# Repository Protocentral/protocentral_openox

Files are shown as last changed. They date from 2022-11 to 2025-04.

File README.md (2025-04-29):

Protocentral OpenOx Wireless Pulse Sensor Kit based on AFE4400/ESP32
========================================

 

## Don't have one? [Buy it here](https://protocentral.com/product/protocentral-openox-pulse-oximeter-breakout-board-kit/)

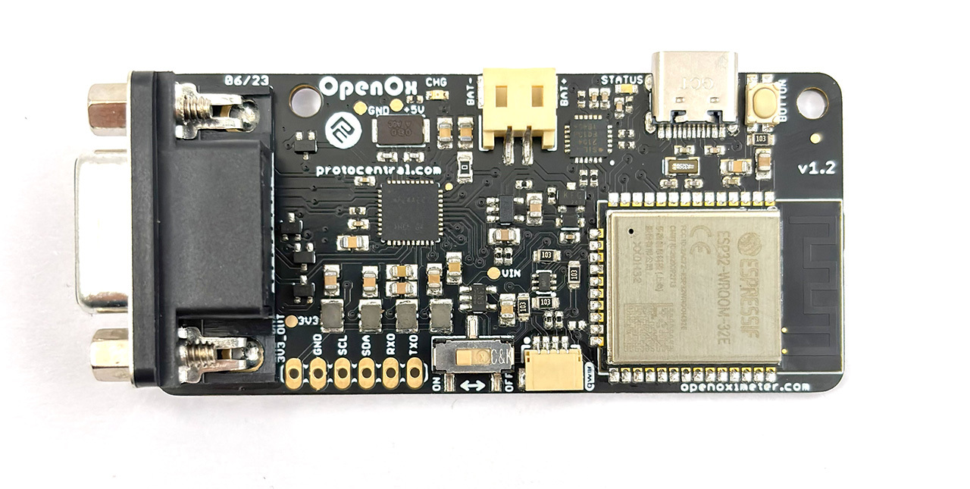
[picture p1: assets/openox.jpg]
Protocentral OpenOx Pulse Oximeter Breakout Board


Protocentral OpenOx is a new standalone, wireless pulse oximetry breakout board that is powered by the ubiquitous ESP32 WROOM32 module and uses the AFE4490 IC to measure oxygen levels in the blood while also providing a PPG waveform, heart rate, and SpO2 values measured with high precision. 

Protocentral OpenOx redefines mobility and wireless capabilities. It functions as a data acquisition system, allowing for continuous real-time monitoring of blood oxygen levels via BLE, which improves the user's medical care within his or her environment as well as medical research opportunities. The standard Nellcor probe is used, which is comfortable to wear, does not restrict the user's freedom of movement, and functions as a battery-powered standalone device.

## Hardware Setup

Connection with the Arduino board is as follows:

 |OpenOx pin label| Arduino Connection  |Pin Function      |
 |:-----------------: |:---------------------:|:------------------:|
 | Tx0              |  -                       |  Serial Data     |
 | RX0              |  -                        |  Serial Clock    |
 | SDA              |  SDA                        |  Power           |
 | SCL              |  SCL                      |  GND             |
 | GND              | GND                     |  Ground          |
 | 3V3              | 3V                      |  3V power supply |

# Visualizing Output

### USB Streaming

* Open the GUI, make sure to select **AFE4490 breakout** under the **Board** dropdown and the appropriate **Port**. If everything goes well, you will be able to see the screen as pictured above.

   <center>

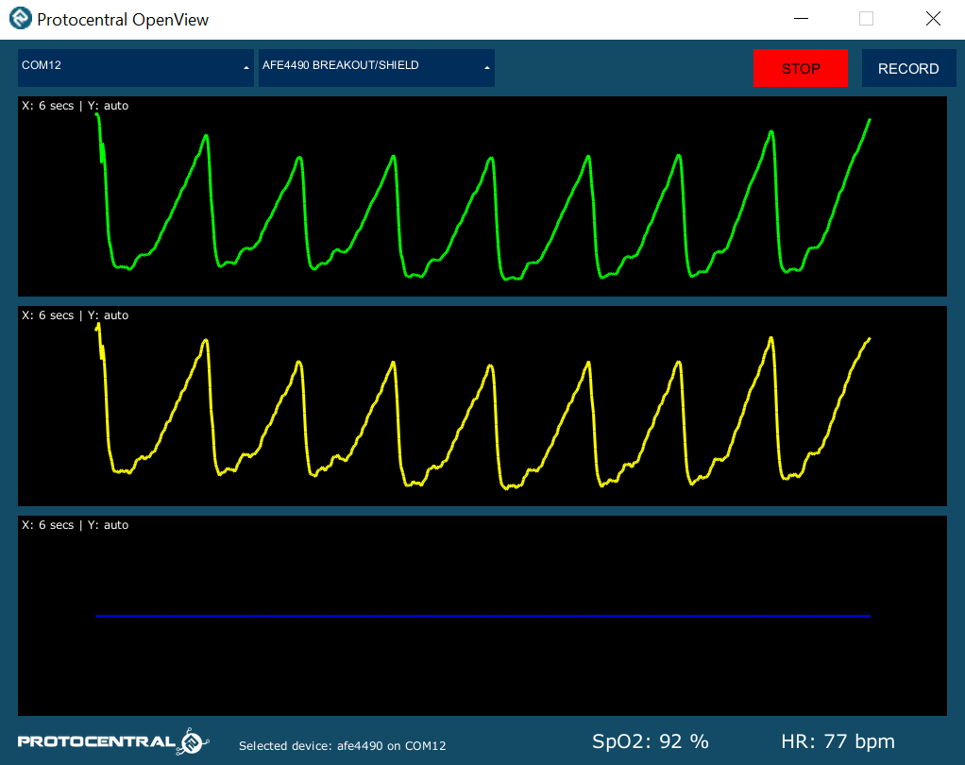
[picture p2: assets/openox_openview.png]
streaming vitals
  

  </center>

### BLE streaming

 <center>

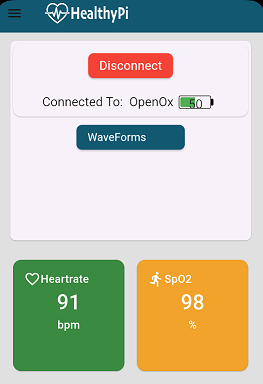
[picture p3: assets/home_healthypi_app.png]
Home
  

  </center>

 <center>

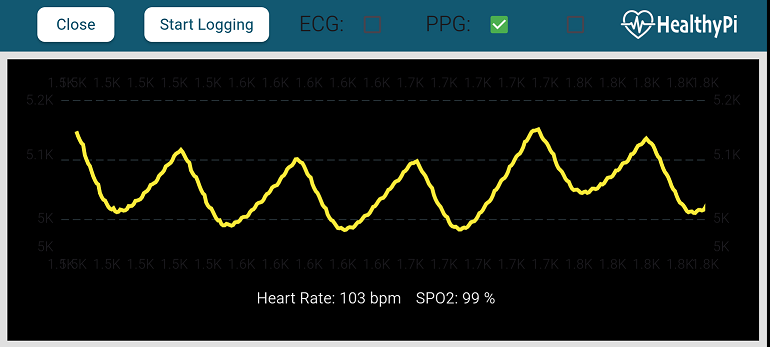
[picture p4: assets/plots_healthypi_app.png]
Plots
  

  </center>

## For further details, refer [the documentation on OpenOx Wireless Pulse Sensor](https://docs.protocentral.com/getting-started-with-openox/)

License Information
===================

License

This product is open source! Both, our hardware and software are open source and licensed under the following licenses:

Hardware
---------

**All hardware is released under the [CERN-OHL-P v2](https://ohwr.org/cern_ohl_p_v2.txt)** license.

Copyright CERN 2020.

This source describes Open Hardware and is licensed under the CERN-OHL-P v2.

You may redistribute and modify this documentation and make products
using it under the terms of the CERN-OHL-P v2 (https:/cern.ch/cern-ohl).
This documentation is distributed WITHOUT ANY EXPRESS OR IMPLIED
WARRANTY, INCLUDING OF MERCHANTABILITY, SATISFACTORY QUALITY
AND FITNESS FOR A PARTICULAR PURPOSE. Please see the CERN-OHL-P v2
for applicable conditions

Software
--------

**All software is released under the MIT License(http://opensource.org/licenses/MIT).**

THE SOFTWARE IS PROVIDED "AS IS", WITHOUT WARRANTY OF ANY KIND, EXPRESS OR IMPLIED, INCLUDING BUT NOT LIMITED TO THE WARRANTIES OF MERCHANTABILITY, FITNESS FOR A PARTICULAR PURPOSE AND NONINFRINGEMENT. IN NO EVENT SHALL THE AUTHORS OR COPYRIGHT HOLDERS BE LIABLE FOR ANY CLAIM, DAMAGES OR OTHER LIABILITY, WHETHER IN AN ACTION OF CONTRACT, TORT OR OTHERWISE, ARISING FROM, OUT OF OR IN CONNECTION WITH THE SOFTWARE OR THE USE OR OTHER DEALINGS IN THE SOFTWARE.

Documentation
-------------
**All documentation is released under [Creative Commons Share-alike 4.0 International](http://creativecommons.org/licenses/by-sa/4.0/).**


You are free to:

* Share — copy and redistribute the material in any medium or format
* Adapt — remix, transform, and build upon the material for any purpose, even commercially.
The licensor cannot revoke these freedoms as long as you follow the license terms.

Under the following terms:

* Attribution — You must give appropriate credit, provide a link to the license, and indicate if changes were made. You may do so in any reasonable manner, but not in any way that suggests the licensor endorses you or your use.
* ShareAlike — If you remix, transform, or build upon the material, you must distribute your contributions under the same license as the original.

Please check [*LICENSE.md*](LICENSE.md) for detailed license descriptions.

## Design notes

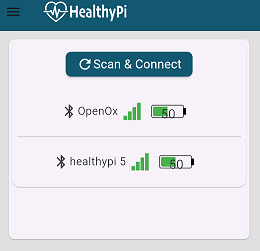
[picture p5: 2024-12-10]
assets/scan_healthypi_app.png

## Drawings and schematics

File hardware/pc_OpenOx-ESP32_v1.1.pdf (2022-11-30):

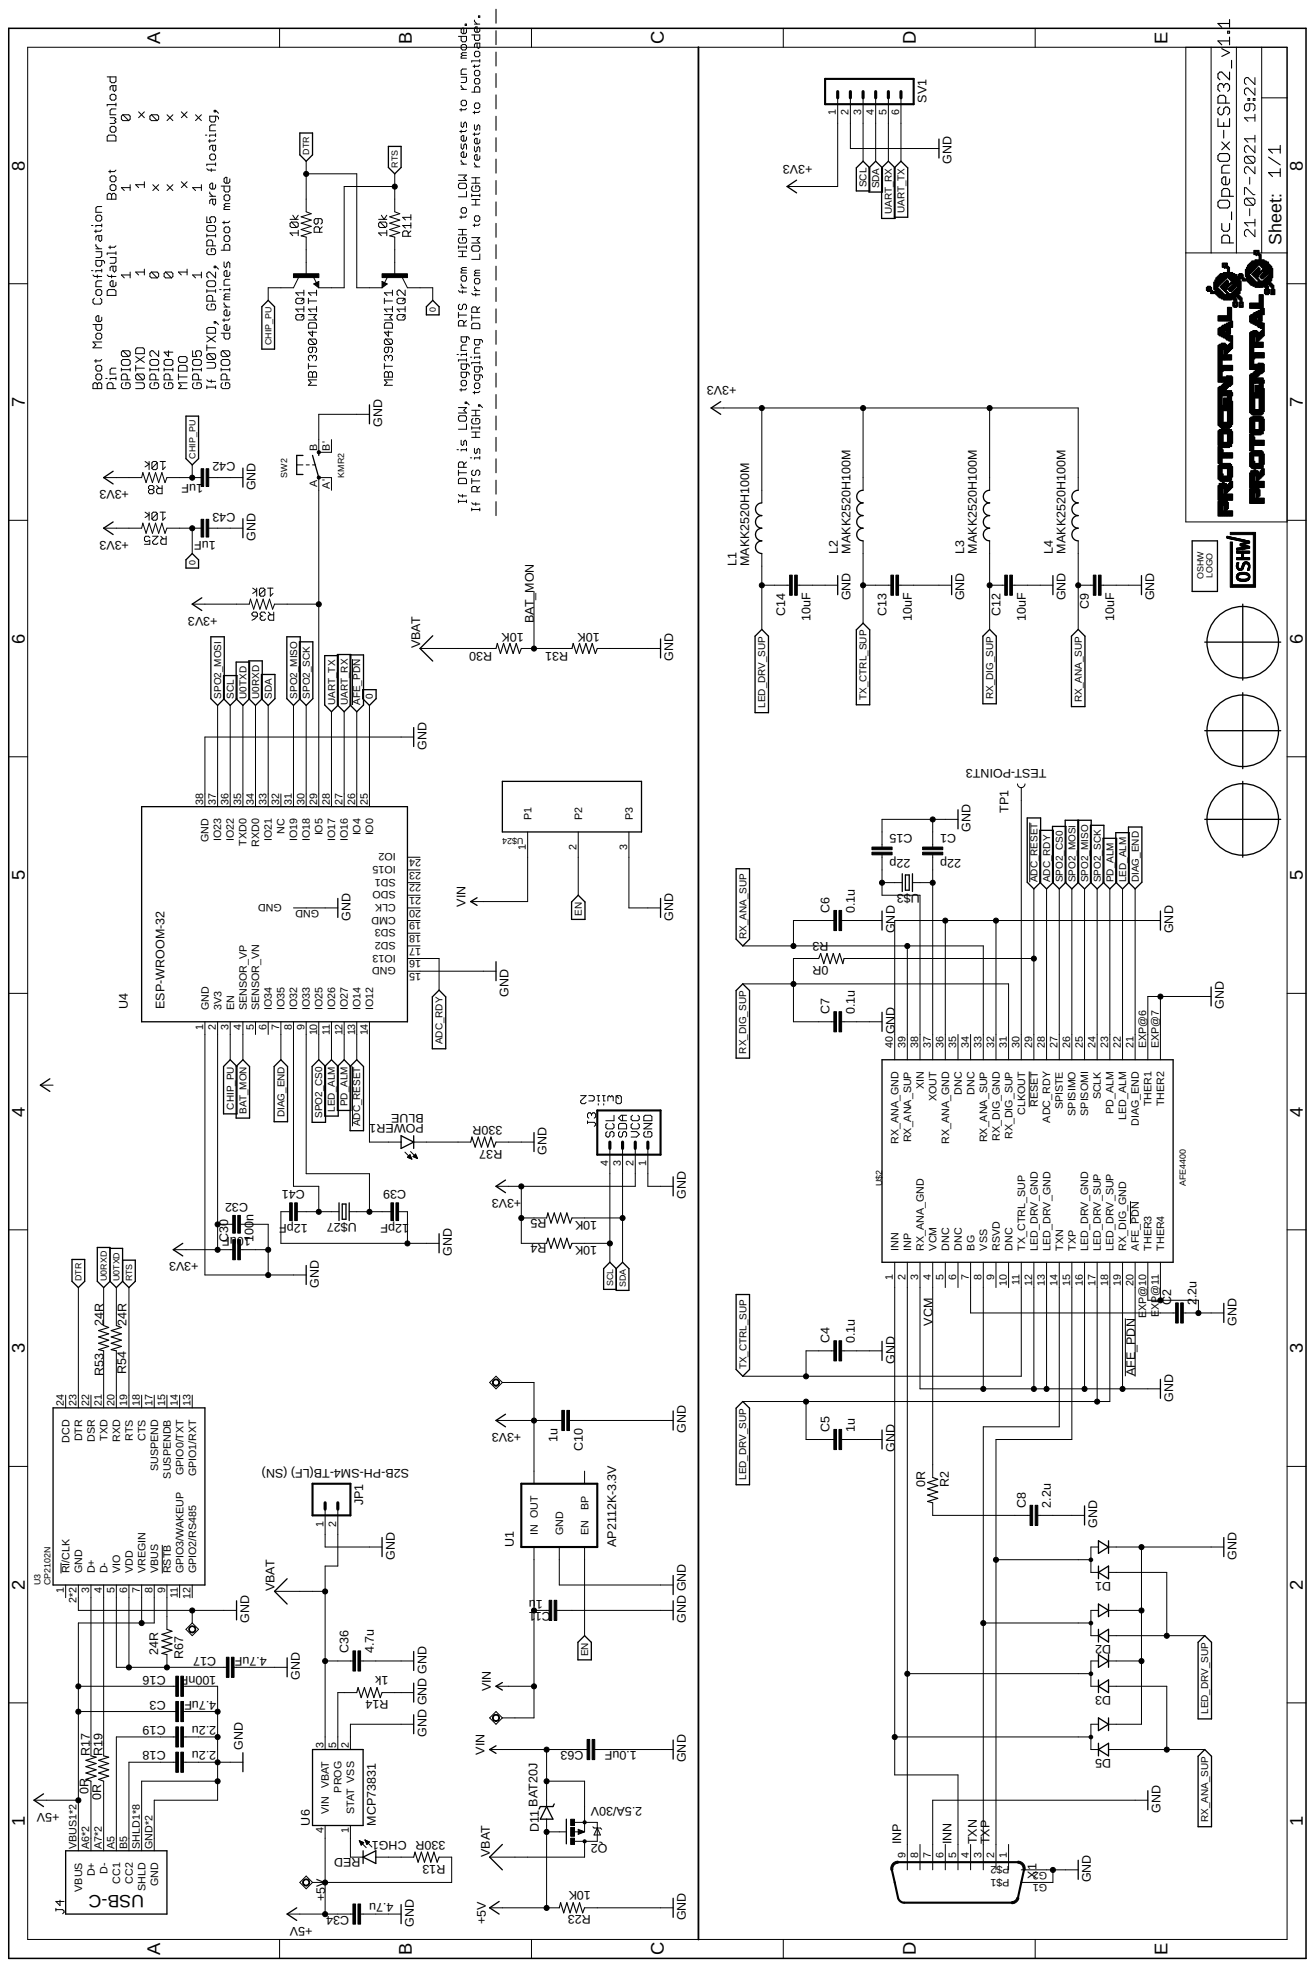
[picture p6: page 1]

THER1 EXP@6 THER2 EXP@7 THER3 EXP@10 THER4 EXP@11

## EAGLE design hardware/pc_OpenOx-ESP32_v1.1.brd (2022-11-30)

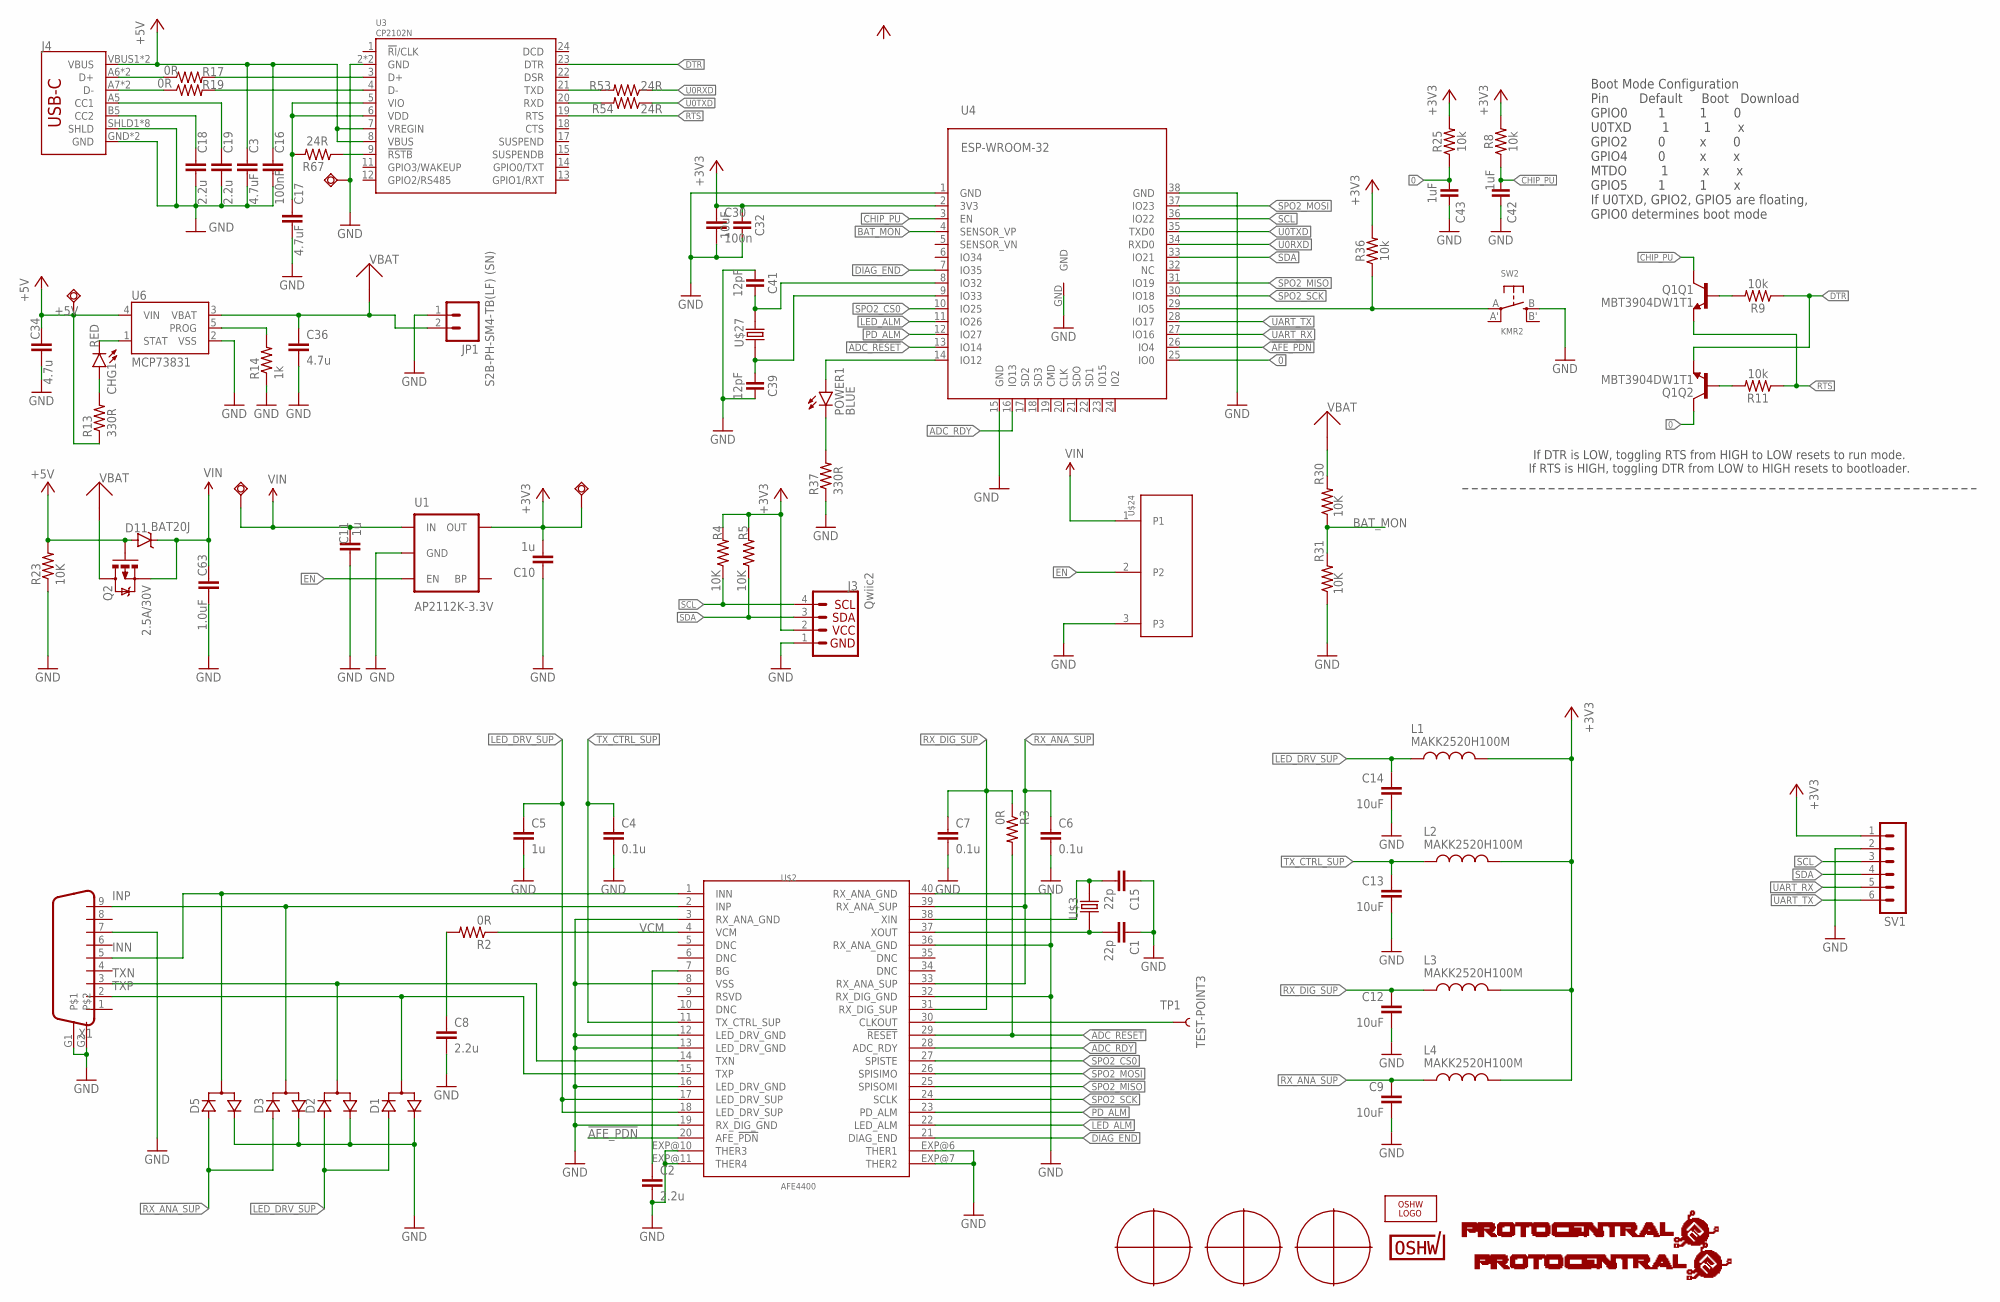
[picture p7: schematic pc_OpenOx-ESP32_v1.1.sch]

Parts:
C1, C15: 22p; C0402
C2, C8, C18, C19: 2.2u; C0402
C3, C17: 4.7uF; C0402
C4, C6, C7: 0.1u; C0805
C5, C10, C11: 1u; C0805
C9, C12, C13, C14, C32: 10uF; C0805
C16: 100nF; C0402
C30: 100n; C0805
C34, C36: 4.7u; C0805
C39, C41: 12pF; C0402
C42, C43: 1uF; C0402
C63: 1.0uF; C0402
CHG1: RED; CHIPLED_0603
D1, D2, D3, D5: D_ACACSOT323; SOT323
D11: BAT20J; SOD-323
J3: Qwiic2; 1X04_1MM_RA
J4: USB_C2-LAYER; USB-C-16P
JP1: S2B-PH-SM4-TB(LF) (SN); JST-2-SMD
L1, L2, L3, L4: MAKK2520H100M; INDC2520X100N
LOGO2: OSHW_LOGO_FILLX0200-NT; OSHW_FILLX200_NOTEXT
POWER1: BLUE; CHIPLED_0603
Q1: MBT3904DW1T1; SC70-6
Q2: 2.5A/30V; SOT23-3
R2, R17, R19: 0R; R0402
R3: 0R; R0805
R4, R5, R23, R30, R31: 10K; R0402
R8, R9, R11, R25, R36: 10k; 0603
R13, R37: 330R; R0402
R14: 1k; R0402
R53, R54, R67: 24R; R0402
SV1: MA06-1
SW2: KMR2; BTN_KMR2_4.6X2.8
SWIO1, SWIO2, SWIO3, SWIO17: TPSQTP13R; TP13R
TP1: TEST-POINT3; PAD.03X.03
U1: AP2112K-3.3V; SOT23-5
U3: CP2102N; QFN24
U4: ESP-WROOM-32
U6: MCP73831; SOT23-5
U$2: AFE4400; QFN-40
U$3: ABM3
U$4: PROTY_LOGO_WITH_TEXT; PROTY_WITH_TEXT
U$5: PROTY-LOGO; LOGO-PROTY
U$7: CERT-SMALL; CERT-SMALL-SILK
U$24: JS102011SCQN
U$27: 520-327-12.5-34B(32.768KHZ); ECX-31B
U$33, U$34, U$35: FUDCIALPOINTS; FIDUCIALPOINTS
X1: DB9

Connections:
0: C43.1, Q1.6 (C), R25.1, U4.25 (IO0)
3.3V: C17.1, R67.2, U3.5 (VIO), U3.6 (VDD)
!ADC_RESET: R3.2, U4.13 (IO14), U$2.29 (!RESET)
!AFE_PDN: U4.26 (IO4), U$2.20 (AFE_!PDN)
+3V3: C10.2, C30.1, C32.1, J3.2, L1.2, L2.2, L3.2, L4.2, R4.2, R5.2, R8.2, R25.2, R36.2, SV1.1, SWIO1.TP, U1.5 (OUT), U4.2 (3V3)
+5V: C3.1, C16.1, C34.1, D11.A, J4.VBUS1 (VBUS), J4.VBUS2 (VBUS), Q2.1 (G), R13.1, R23.2, SWIO3.TP, U3.7 (VREGIN), U3.8 (VBUS), U6.4 (VIN)
ADC_RDY: U4.16 (IO13), U$2.28 (ADC_RDY)
BAT_MON: R30.1, R31.2, U4.4 (SENSOR_VP)
CHIP_PU: C42.1, Q1.3 (C), R8.1, U4.3 (EN)
DIAG_END: U4.7 (IO35), U$2.21 (DIAG_END)
DTR: Q1.1 (E), R9.1, U3.23 (DTR)
EN: U1.3 (EN), U$24.2
GND: C1.1, C2.2, C3.2, C4.2, C5.2, C6.2, C7.2, C8.2, C9.2, C10.1, C11.1, C12.2, C13.2, C14.2, C15.1, C16.2, C17.2, C18.2, C19.2, C30.2, C32.2, C34.2, C36.2, C39.2, C41.1, C42.2, C43.2, C63.2, D1.2 (C), D2.2 (C), D3.2 (C), D5.2 (C), J3.1, J4.GND, J4.GND2 (GND), J4.SHLD1 (SHLD), J4.SHLD2 (SHLD), J4.SHLD3 (SHLD), J4.SHLD4 (SHLD), J4.SHLD5 (SHLD), J4.SHLD6 (SHLD), J4.SHLD7 (SHLD), J4.SHLD8 (SHLD), JP1.1, R14.1, R23.1, R31.1, R37.1, SV1.2, SW2.B (S), SWIO17.TP, U1.2 (GND), U3.2 (GND), U3.PAD (GND), U4.1 (GND), U4.15 (GND), U4.38 (GND), U4.GND, U6.2 (VSS), U$2.3 (RX_ANA_GND), U$2.8 (VSS), U$2.12 (LED_DRV_GND), U$2.13 (LED_DRV_GND), U$2.16 (LED_DRV_GND), U$2.19 (RX_DIG_GND), U$2.32 (RX_DIG_GND), U$2.36 (RX_ANA_GND), U$2.40 (RX_ANA_GND), U$2.EXP@6 (THER1), U$2.EXP@7 (THER2), U$2.EXP@10 (THER3), U$2.EXP@11 (THER4), U$24.3, X1.7, X1.G1, X1.G2
INN: D5.1 (CA), U$2.1 (INN), X1.5
INP: D3.1 (CA), U$2.2 (INP), X1.9
LED_ALM: U4.11 (IO26), U$2.22 (LED_ALM)
LED_DRV_SUP: C5.1, C14.1, D1.3 (A), D2.3 (A), L1.1, U$2.17 (LED_DRV_SUP), U$2.18 (LED_DRV_SUP)
unnamed: C1.2, U$2.37 (XOUT), U$3.1
unnamed: R67.1, U3.9 (!RSTB)
unnamed: C8.1, R2.2
unnamed: C19.1, J4.A5 (CC1)
unnamed: C18.1, J4.B5 (CC2)
unnamed: R17.2, U3.3 (D+)
unnamed: R19.2, U3.4 (D-)
unnamed: J4.A6 (D+), J4.B6 (D+), R17.1
unnamed: C15.2, U$2.38 (XIN), U$3.2
unnamed: C2.1, U$2.7 (BG)
unnamed: J4.A7 (D-), J4.B7 (D-), R19.1
unnamed: TP1.P$1, U$2.30 (CLKOUT)
unnamed: Q1.5 (B), R9.2
unnamed: Q1.2 (B), R11.2
unnamed: CHG1.C, U6.1 (STAT)
unnamed: CHG1.A, R13.2
unnamed: R14.2, U6.5 (PROG)
unnamed: C41.2, U4.8 (IO32), U$27.P$2 (2)
unnamed: C39.1, U4.9 (IO33), U$27.P$1 (1)
unnamed: R36.1, SW2.A, U4.29 (IO5)
unnamed: POWER1.A, U4.14 (IO12)
unnamed: POWER1.C, R37.2
PD_ALM: U4.12 (IO27), U$2.23 (PD_ALM)
RTS: Q1.4 (E), R11.1, U3.19 (RTS)
RX: R54.2, U3.20 (RXD)
RX_ANA_SUP: C6.1, C9.1, D3.3 (A), D5.3 (A), L4.1, U$2.33 (RX_ANA_SUP), U$2.39 (RX_ANA_SUP)
RX_DIG_SUP: C7.1, C12.1, L3.1, R3.1, U$2.31 (RX_DIG_SUP)
SCL: J3.4, R4.1, SV1.3, U4.36 (IO22)
SDA: J3.3, R5.1, SV1.4, U4.33 (IO21)
SPO2_CS0: U4.10 (IO25), U$2.27 (SPISTE)
SPO2_MISO: U4.31 (IO19), U$2.25 (SPISOMI)
SPO2_MOSI: U4.37 (IO23), U$2.26 (SPISIMO)
SPO2_SCK: U4.30 (IO18), U$2.24 (SCLK)
TX: R53.2, U3.21 (TXD)
TXN: D2.1 (CA), U$2.14 (TXN), X1.3
TXP: D1.1 (CA), U$2.15 (TXP), X1.2
TX_CTRL_SUP: C4.1, C13.1, L2.1, U$2.11 (TX_CTRL_SUP)
U0RXD: R53.1, U4.34 (RXD0)
U0TXD: R54.1, U4.35 (TXD0)
UART_RX: SV1.5, U4.27 (IO16)
UART_TX: SV1.6, U4.28 (IO17)
VBAT: C36.1, JP1.2, Q2.3 (D), R30.2, U6.3 (VBAT)
VCM: R2.1, U$2.4 (VCM)
VIN: C11.2, C63.1, D11.C, Q2.2 (S), SWIO2.TP, U1.1 (IN), U$24.1

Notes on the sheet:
Boot Mode Configuration Pin Default Boot Download GPIO0 1 1 0 U0TXD 1 1 x GPIO2 0 x 0 GPIO4 0 x x MTDO 1 x x GPIO5 1 1 x If U0TXD, GPIO2, GPIO5 are floating, GPIO0 determines boot mode
If DTR is LOW, toggling RTS from HIGH to LOW resets to run mode. If RTS is HIGH, toggling DTR from LOW to HIGH resets to bootloader.

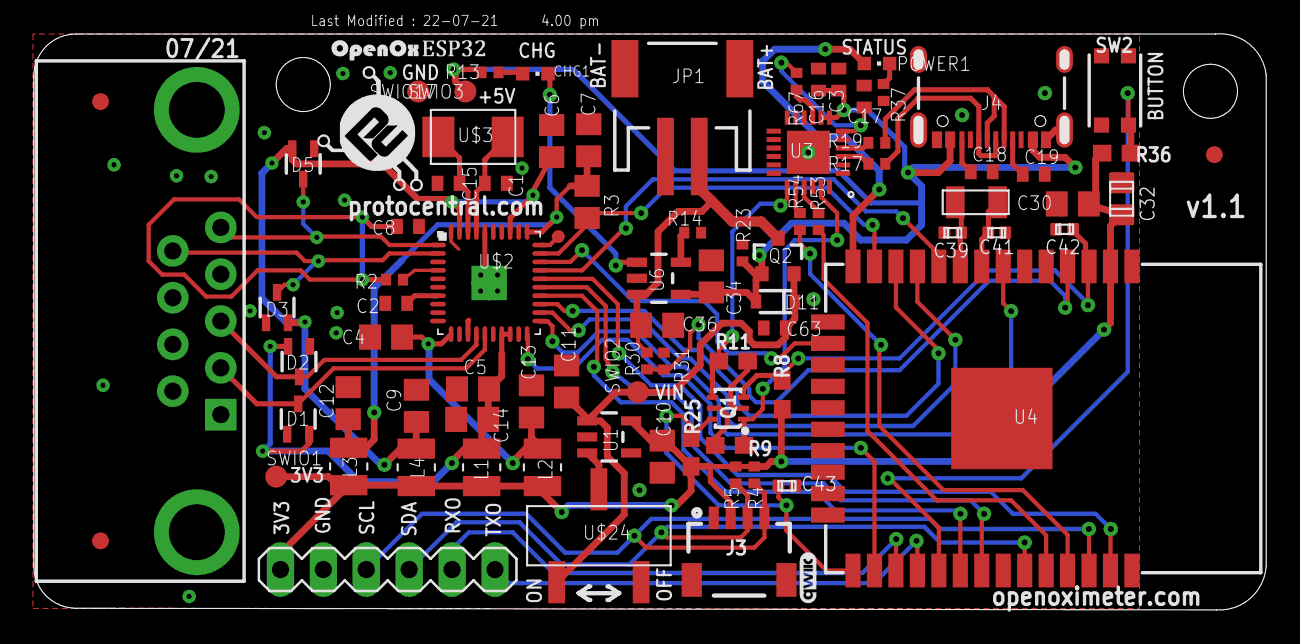
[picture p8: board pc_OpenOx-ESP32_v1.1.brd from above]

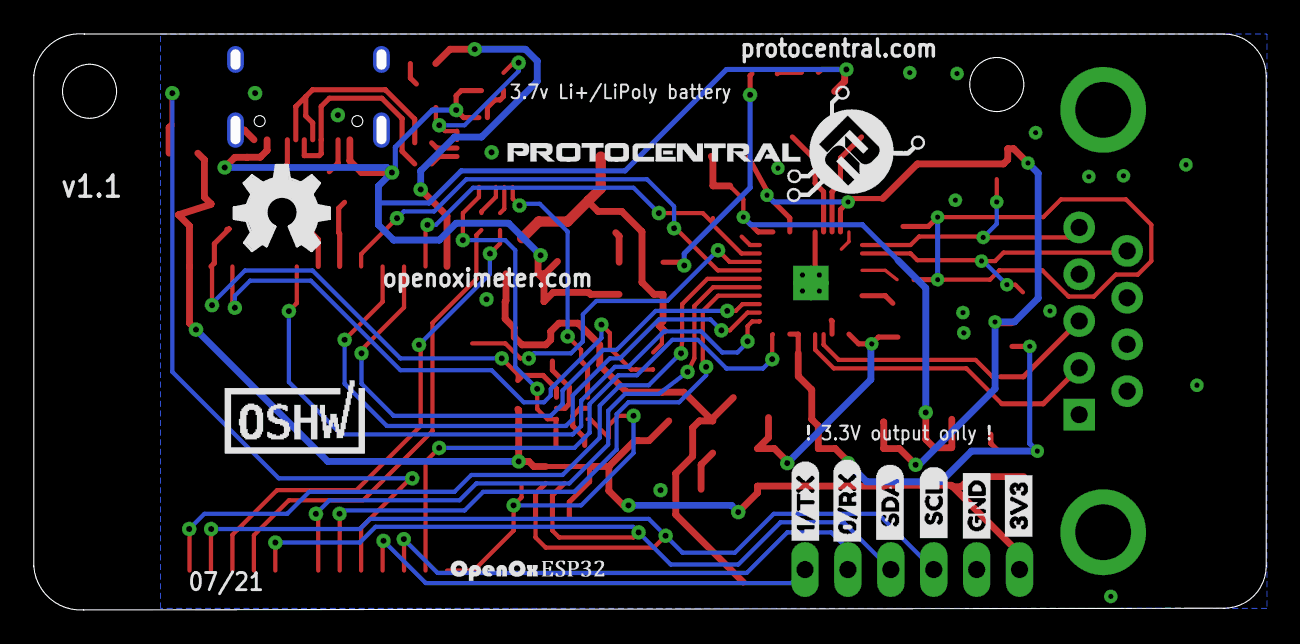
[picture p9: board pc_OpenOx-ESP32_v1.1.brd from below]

Board: 4 copper layers, 73.0 x 34.1 mm, 97 parts (11 on the bottom side), 61 nets.

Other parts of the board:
LOGO4: QWIIC_LOGO_3MM; QWIIC_3MM
U$6: 3V32
U$8, U$12: OPENOXLOGO1
U$9: _SCL16
U$10: _SDA17
U$13: GND0
U$16: PULSE
U$44: 1#TX1
U$48: 0#RX0

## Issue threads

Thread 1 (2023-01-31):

Incorrect HR

yashm, 2023-01-31:
Hello folks,
The OpenOx-USB-Output prints an incorrect heart rate.,
SPO2 is close to actual, but HR is way off:
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

Any pointers on what parameters to tweak?

protocentralashwin, 2023-01-31:
Thank you for reporting @yashm We will check and get back

yashm, 2023-01-31:
Thank you @protocentralashwin , will post some other minor PCB changes that I would recommend once this is solved.

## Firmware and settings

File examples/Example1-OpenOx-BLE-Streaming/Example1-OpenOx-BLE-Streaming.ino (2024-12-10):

//////////////////////////////////////////////////////////////////////////////////////////
//
//    This example is for the new Open-Ox board.
//
//    This software is licensed under the MIT License(http://opensource.org/licenses/MIT).
//
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
//   For information on how to use, visit https://github.com/Protocentral/protocentral-afe4490-arduino
/////////////////////////////////////////////////////////////////////////////////////////


#include <SPI.h>
#include <protocentral_afe44xx.h>

#include <BLEDevice.h>
#include <BLEServer.h>
#include <BLEUtils.h>
#include <BLE2902.h>

#define Heartrate_SERVICE_UUID (uint16_t(0x180D))
#define Heartrate_CHARACTERISTIC_UUID (uint16_t(0x2A37))
#define sp02_SERVICE_UUID (uint16_t(0x1822))
#define sp02_CHARACTERISTIC_UUID (uint16_t(0x2A5E))
#define HRV_SERVICE_UUID "cd5c7491-4448-7db8-ae4c-d1da8cba36d0"
#define HIST_CHARACTERISTIC_UUID "cd5c1525-4448-7db8-ae4c-d1da8cba36d0"
#define DATASTREAM_SERVICE_UUID (uint16_t(0x1122))
#define DATASTREAM_CHARACTERISTIC_UUID (uint16_t(0x1424))

#define AFE44XX_CS_PIN   25
#define AFE44XX_DRDY_PIN 13
#define AFE44XX_PWDN_PIN 4

AFE44XX afe44xx(AFE44XX_CS_PIN, AFE44XX_PWDN_PIN);

afe44xx_data afe44xx_raw_data;
uint8_t ppg_data_buff[20];
int16_t ppg_wave_ir;
uint16_t ppg_stream_cnt = 0;
uint8_t sp02;
uint8_t heartrate;
bool ppg_buf_ready = false;
bool spo2_calc_done = false;
bool heartrate_calc_done = false;
bool deviceConnected = false;
bool oldDeviceConnected = false;

String strValue = "";

BLEServer *pServer = NULL;
BLECharacteristic *Heartrate_Characteristic = NULL;
BLECharacteristic *sp02_Characteristic = NULL;
BLECharacteristic *hist_Characteristic = NULL;
BLECharacteristic *hrv_Characteristic = NULL;
BLECharacteristic *datastream_Characteristic = NULL;

class MyServerCallbacks : public BLEServerCallbacks
{
  void onConnect(BLEServer *pServer)
  {
    deviceConnected = true;
    Serial.println("connected");
  }

  void onDisconnect(BLEServer *pServer)
  {
    deviceConnected = false;
    Serial.println("disconnected");
  }
};

class MyCallbackHandler : public BLECharacteristicCallbacks
{
  void onWrite(BLECharacteristic *datastream_Characteristic)
  {
    std::string value = datastream_Characteristic->getValue();
    int len = value.length();
    strValue = "0";

    if (value.length() > 0)
    {
      Serial.print("New value: ");

      for (int i = 0; i < value.length(); i++)
      {
        Serial.print(String(value[i]));
        strValue += value[i];
      }

      Serial.println();
    }
  }
};

void OpenOx_BLE_Init()
{
  BLEDevice::init("OpenOx");     // Create the BLE Device
  pServer = BLEDevice::createServer(); // Create the BLE Server
  pServer->setCallbacks(new MyServerCallbacks());
  BLEService *HeartrateService = pServer->createService(Heartrate_SERVICE_UUID); // Create the BLE Service
  BLEService *sp02Service = pServer->createService(sp02_SERVICE_UUID);           // Create the BLE Service
  BLEService *hrvService = pServer->createService(HRV_SERVICE_UUID);
  BLEService *datastreamService = pServer->createService(DATASTREAM_SERVICE_UUID);

  Heartrate_Characteristic = HeartrateService->createCharacteristic(
      Heartrate_CHARACTERISTIC_UUID,
      BLECharacteristic::PROPERTY_READ |
          BLECharacteristic::PROPERTY_WRITE |
          BLECharacteristic::PROPERTY_NOTIFY);

  sp02_Characteristic = sp02Service->createCharacteristic(
      sp02_CHARACTERISTIC_UUID,
      BLECharacteristic::PROPERTY_READ |
          BLECharacteristic::PROPERTY_WRITE |
          BLECharacteristic::PROPERTY_NOTIFY);
 
  hist_Characteristic = hrvService->createCharacteristic(
      HIST_CHARACTERISTIC_UUID,
      BLECharacteristic::PROPERTY_READ |
          BLECharacteristic::PROPERTY_WRITE |
          BLECharacteristic::PROPERTY_NOTIFY);   

  datastream_Characteristic = datastreamService->createCharacteristic(
      DATASTREAM_CHARACTERISTIC_UUID,
      BLECharacteristic::PROPERTY_READ |
          BLECharacteristic::PROPERTY_WRITE |
          BLECharacteristic::PROPERTY_NOTIFY);  

  Heartrate_Characteristic->addDescriptor(new BLE2902());
  sp02_Characteristic->addDescriptor(new BLE2902());     
  hist_Characteristic->addDescriptor(new BLE2902());
  datastream_Characteristic->addDescriptor(new BLE2902());
  datastream_Characteristic->setCallbacks(new MyCallbackHandler());

  // Start the service
  HeartrateService->start();
  sp02Service->start();
  hrvService->start(); 
  datastreamService->start(); 

  // Start advertising
  BLEAdvertising *pAdvertising = BLEDevice::getAdvertising();
  pAdvertising->addServiceUUID(Heartrate_SERVICE_UUID);
  pAdvertising->addServiceUUID(sp02_SERVICE_UUID);
  pAdvertising->addServiceUUID(HRV_SERVICE_UUID);
  pAdvertising->addServiceUUID(DATASTREAM_SERVICE_UUID);
  pAdvertising->setScanResponse(false);
  pAdvertising->setMinPreferred(0x00); // set value to 0x00 to not advertise this parameter
  BLEDevice::startAdvertising();
  Serial.println("Waiting a client connection to notify...");
}

void handle_ble_stack()
{

   
 if (ppg_buf_ready)
  {
    ppg_buf_ready = false;
    hist_Characteristic->setValue(ppg_data_buff, 19);
    hist_Characteristic->notify();
  }

  if (spo2_calc_done)
  {
    // afe44xx_raw_data.buffer_count_overflow = false;
    uint8_t spo2_att_ble[5];
    spo2_att_ble[0] = 0x00;
    spo2_att_ble[1] = (uint8_t)sp02;
    spo2_att_ble[2] = (uint8_t)(sp02 >> 8);
    spo2_att_ble[3] = (uint8_t)heartrate;;
    spo2_att_ble[4] = (uint8_t)(heartrate >> 8);
    sp02_Characteristic->setValue(spo2_att_ble, 5);
    sp02_Characteristic->notify();
    spo2_calc_done = false;
  }

if (heartrate_calc_done)
  {
    // afe44xx_raw_data.buffer_count_overflow = false;
    uint8_t heartrate_att_ble[5];
    heartrate_att_ble[0] = 0x00;
    heartrate_att_ble[1] = (uint8_t)heartrate;
    heartrate_att_ble[2] = (uint8_t)(heartrate >> 8);
    Heartrate_Characteristic->setValue(heartrate_att_ble, 3);
    Heartrate_Characteristic->notify();
    heartrate_calc_done = false;
  }  

   if (!deviceConnected && oldDeviceConnected)
  {
    delay(500);                  // give the bluetooth stack the chance to get things ready
    pServer->startAdvertising(); // restart advertising
    Serial.println("start advertising");
    oldDeviceConnected = deviceConnected;
  }

   // connecting
  if (deviceConnected && !oldDeviceConnected)
  {
    // do stuff here on connecting
    oldDeviceConnected = deviceConnected;
  }

}
  
    
void setup()
{
  Serial.begin(57600);
  Serial.println("Intilaziting AFE44xx.. ");
  delay(2000) ;   // pause for a moment
  
  OpenOx_BLE_Init();
  SPI.begin();

  afe44xx.afe44xx_init();
  Serial.println("Inited...");
}


void loop()
{
    delay(8);
    
    afe44xx.get_AFE44XX_Data(&afe44xx_raw_data);
    ppg_wave_ir = (int16_t)(afe44xx_raw_data.IR_data >> 8);
    ppg_wave_ir = ppg_wave_ir;

    ppg_data_buff[ppg_stream_cnt++] = (uint8_t)ppg_wave_ir;
    ppg_data_buff[ppg_stream_cnt++] = (ppg_wave_ir >> 8);

    if (ppg_stream_cnt >= 19)
    {
      ppg_buf_ready = true;
      ppg_stream_cnt = 0;
    }

    if (afe44xx_raw_data.buffer_count_overflow)
    {

      if (afe44xx_raw_data.spo2 == -999)
      {
        sp02 = 0;
        heartrate = 0;
      }
      else
      {
        sp02 = (uint8_t)afe44xx_raw_data.spo2;
        spo2_calc_done = true;
        heartrate = (uint8_t) afe44xx_raw_data.heart_rate;
        heartrate_calc_done = true;
      }

      
      afe44xx_raw_data.buffer_count_overflow = false;
    }
    handle_ble_stack();
}

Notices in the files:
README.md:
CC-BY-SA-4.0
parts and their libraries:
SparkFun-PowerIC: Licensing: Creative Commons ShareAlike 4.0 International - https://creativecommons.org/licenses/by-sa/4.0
